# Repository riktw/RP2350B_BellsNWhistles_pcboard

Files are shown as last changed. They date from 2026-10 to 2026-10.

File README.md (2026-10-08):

## PCBoard for RP2350B BellsNWhistles

This contains the kicad files for a little board that turns the [RP2350B BellsNWhistles](https://github.com/riktw/RP2350B_BellsNWhistles) board into a small computer.
It has all the modern and some retro IO like:

- 3 x USB
- PS/2 for mouse and keyboard
- NES controller
- Audio via 3.5mm
- MicroSD for storage
- On board RTC

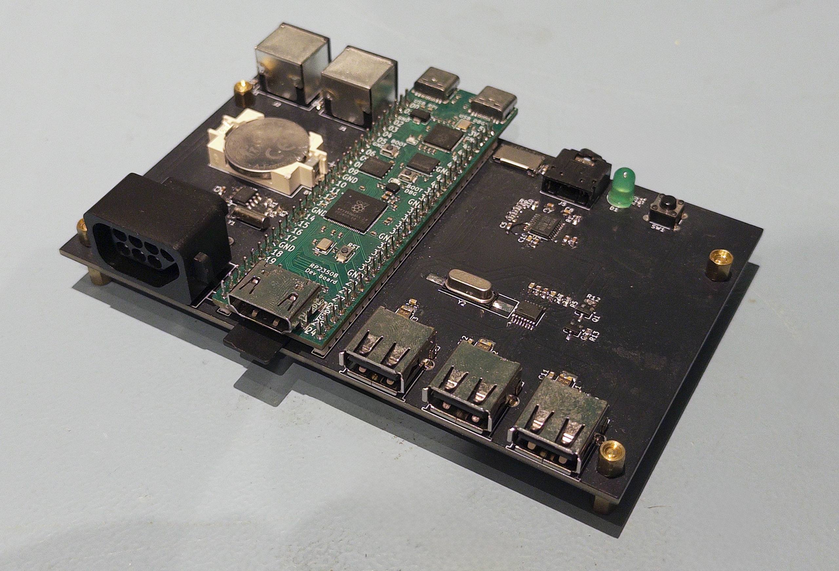
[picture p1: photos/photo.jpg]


This board is tested and no bugs should remain in the latest version.

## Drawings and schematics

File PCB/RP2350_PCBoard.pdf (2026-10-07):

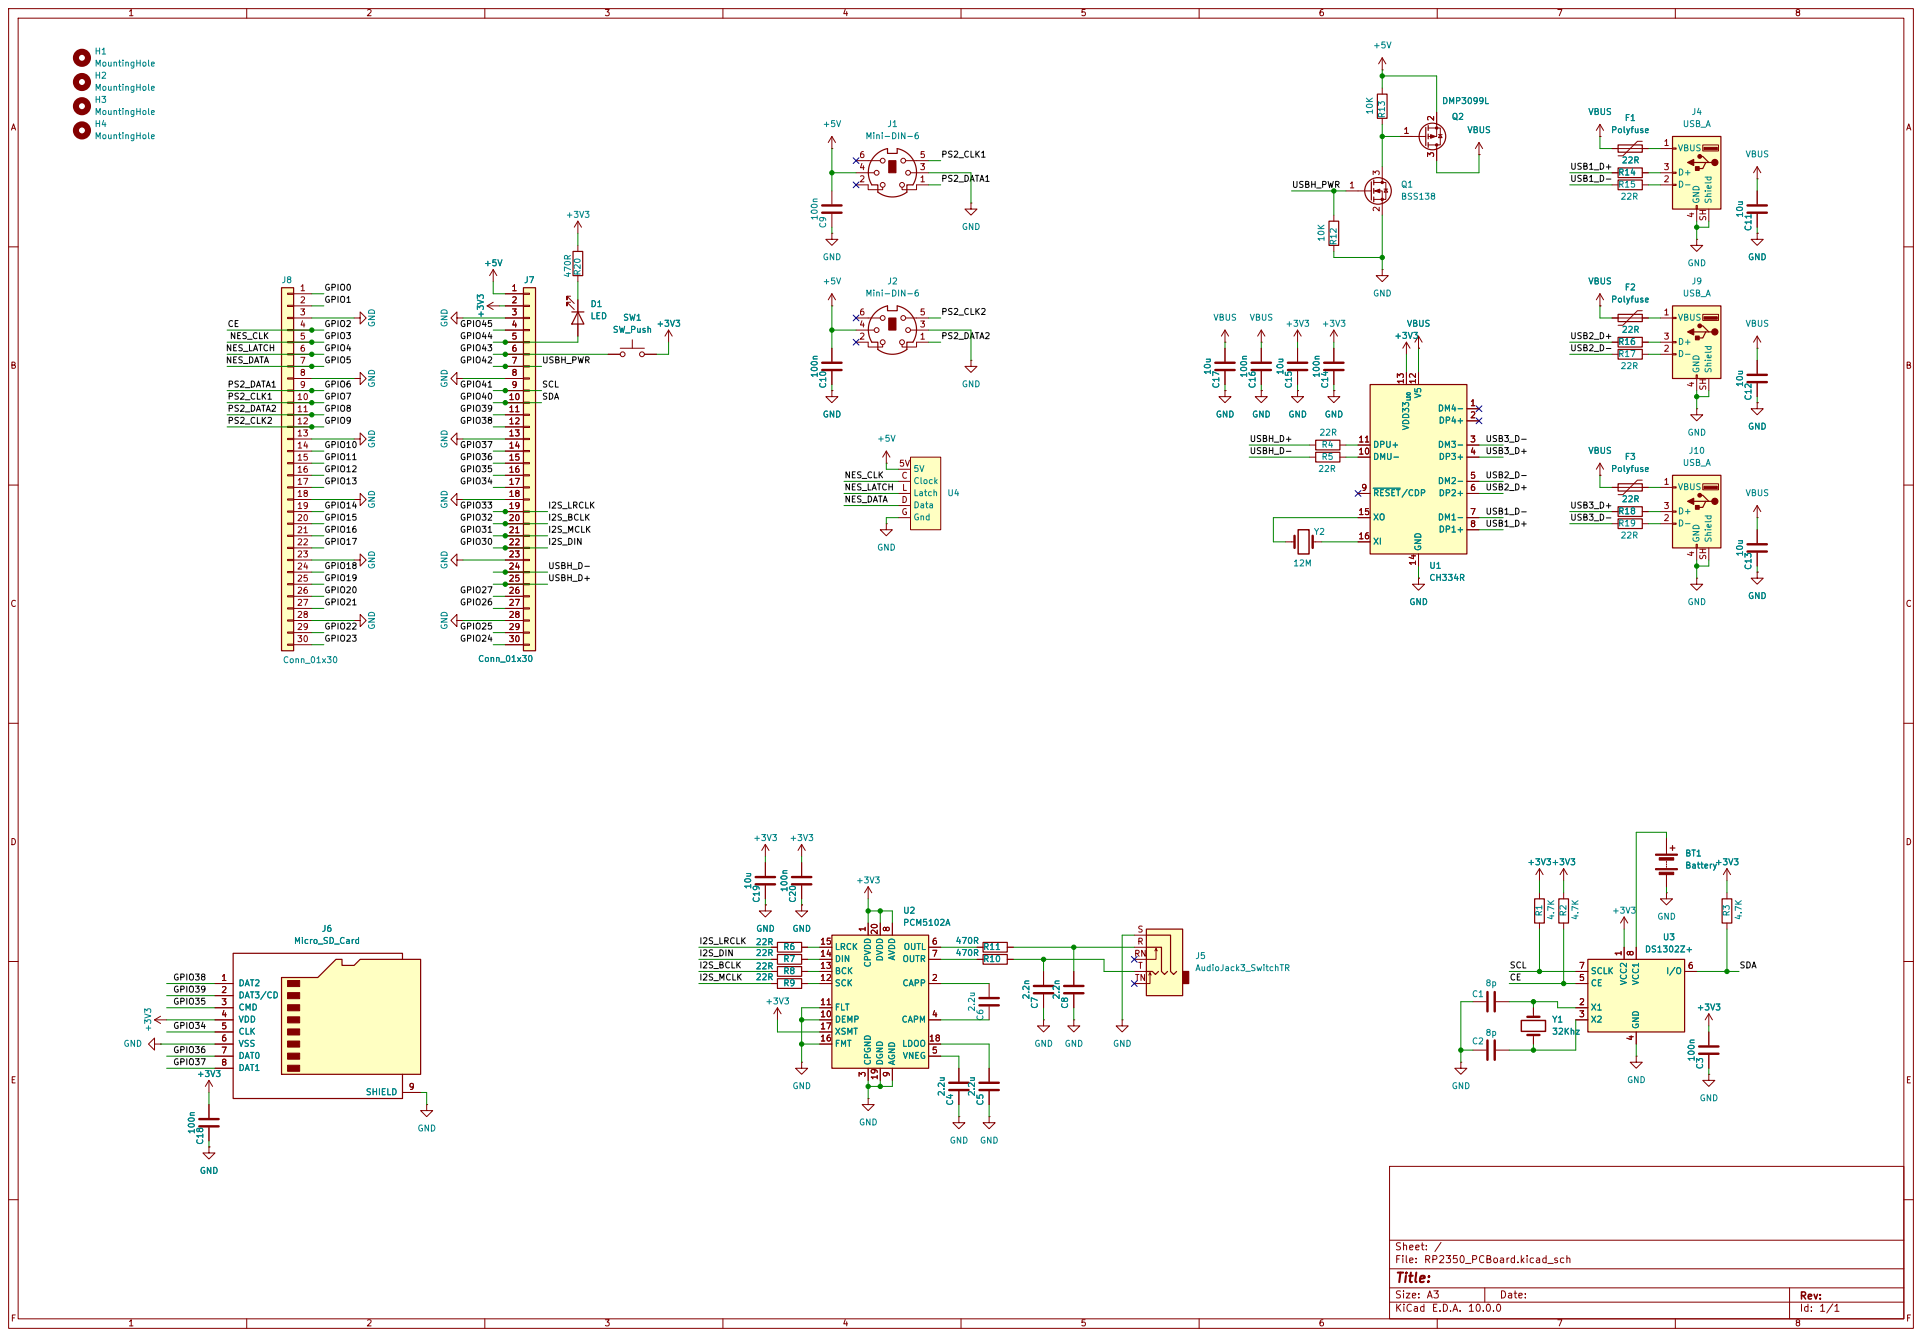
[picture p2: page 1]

Size: A3 | Rev: | F Date:
KiCad E.D.A. 10.0.0 | Id: 1/1

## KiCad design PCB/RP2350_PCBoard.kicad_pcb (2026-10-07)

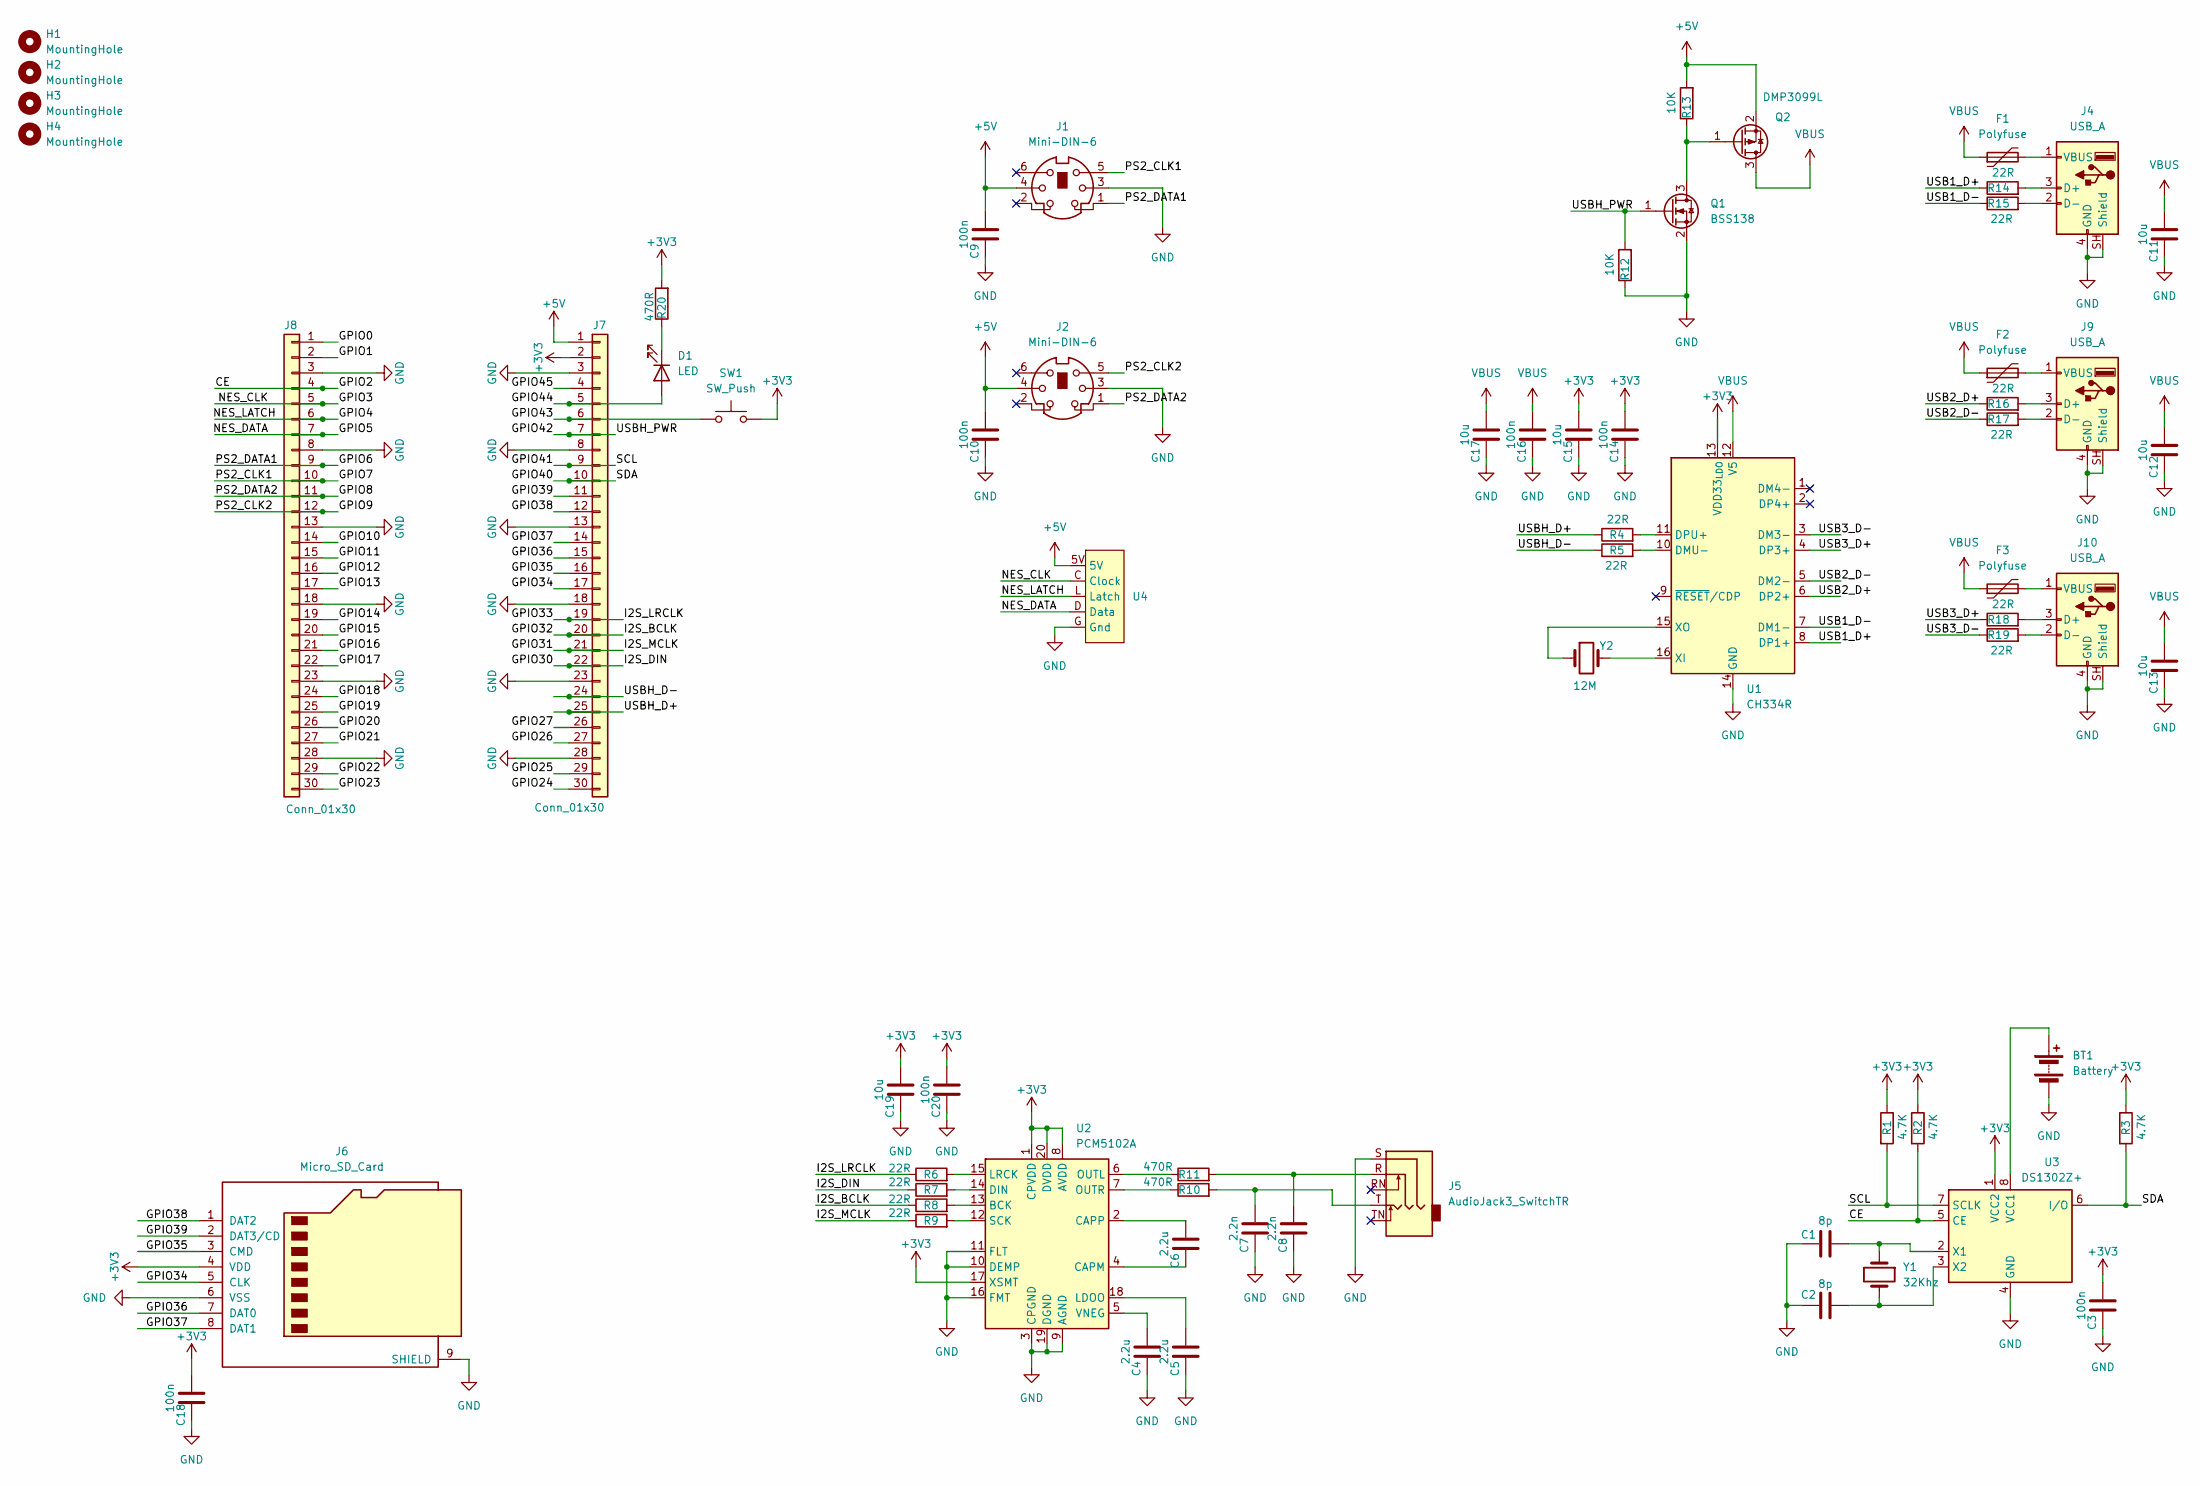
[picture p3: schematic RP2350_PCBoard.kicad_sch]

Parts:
BT1: Battery; BatteryHolder_Keystone_1060_1x2032; LCSC C70377
C1, C2: 8p; C_0603_1608Metric_Pad1.08x0.95mm_HandSolder
C3, C9, C10, C14, C16, C18, C20: 100n; C_0603_1608Metric_Pad1.08x0.95mm_HandSolder
C4, C5, C6: 2.2u; C_0603_1608Metric_Pad1.08x0.95mm_HandSolder
C7, C8: 2.2n; C_0603_1608Metric_Pad1.08x0.95mm_HandSolder
C11, C12, C13, C15, C17, C19: 10u; C_0603_1608Metric_Pad1.08x0.95mm_HandSolder
D1: LED; LED_D5.0mm
F1, F2, F3: Polyfuse; C_1812_4532Metric_Pad1.57x3.40mm_HandSolder
H1, H2, H3, H4: MountingHole; MountingHole_3.2mm_M3
J1, J2: Mini-DIN-6; Connector_Mini-DIN_Female_6Pin_2rows
J4, J9, J10: USB_A; USB_A_Molex_67643_Horizontal
J5: AudioJack3_SwitchTR; Jack_3.5mm_CUI_SJ1-3525N_Horizontal
J6: Micro_SD_Card; microSD Hanbo Electronic TF-018; LCSC C961679
J7, J8: Conn_01x30; PinHeader_1x30_P2.54mm_Vertical
Q1: BSS138; SOT-23_Handsoldering; LCSC C82045
Q2: DMP3099L; SOT-23_Handsoldering; LCSC C148354
R1, R2, R3: 4.7K; R_0603_1608Metric_Pad0.98x0.95mm_HandSolder
R4, R5, R6, R7, R8, R9, R14, R15, R16, R17, R18, R19: 22R; R_0603_1608Metric_Pad0.98x0.95mm_HandSolder
R10, R11, R20: 470R; R_0603_1608Metric_Pad0.98x0.95mm_HandSolder
R12, R13: 10K; R_0603_1608Metric_Pad0.98x0.95mm_HandSolder
SW1: SW_Push; SW_PUSH_6mm_H5mm
U1: CH334R; QSOP-16_3.9x4.9mm_P0.635mm; LCSC C4154405
U2: PCM5102A; TSSOP-20_4.4x6.5mm_P0.65mm; LCSC C107671
U3: DS1302Z+; SOIC-8_3.9x4.9mm_P1.27mm; LCSC C8959
U4: NES controller port
Y1: 32Khz; Crystal_DS26_D2.0mm_L6.0mm_Horizontal; LCSC C52082
Y2: 12M; Crystal_SMD_HC49-SD_HandSoldering; LCSC C14871

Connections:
+3V3: C3.2, C14.2, C15.2, C18.2, C19.2, C20.2, J6.4 (VDD), J7.2, R1.1, R2.1, R3.1, R20.2, SW1.2, U1.13 (VDD33_{LDO}), U2.1 (CPVDD), U2.8 (AVDD), U2.17 (XSMT), U2.20 (DVDD), U3.1 (VCC2)
+5V: C9.2, C10.2, J1.4, J2.4, J7.1, Q2.2 (S), R13.2, U4.5V
/CE: J8.4, R2.2, U3.5 (CE)
/GPIO0: J8.1
/GPIO1: J8.2
/GPIO3: J8.5, U4.C (Clock)
/GPIO4: J8.6, U4.L (Latch)
/GPIO5: J8.7, U4.D (Data)
/GPIO6: J1.1, J8.9
/GPIO7: J1.5, J8.10
/GPIO8: J2.1, J8.11
/GPIO9: J2.5, J8.12
/GPIO10: J8.14
/GPIO11: J8.15
/GPIO12: J8.16
/GPIO13: J8.17
/GPIO14: J8.19
/GPIO15: J8.20
/GPIO16: J8.21
/GPIO17: J8.22
/GPIO18: J8.24
/GPIO19: J8.25
/GPIO20: J8.26
/GPIO21: J8.27
/GPIO22: J8.29
/GPIO23: J8.30
/GPIO24: J7.30
/GPIO25: J7.29
/GPIO26: J7.27
/GPIO27: J7.26
/GPIO30: J7.22, R7.1
/GPIO31: J7.21, R9.1
/GPIO32: J7.20, R8.1
/GPIO33: J7.19, R6.1
/GPIO34: J6.5 (CLK), J7.17
/GPIO35: J6.3 (CMD), J7.16
/GPIO36: J6.7 (DAT0), J7.15
/GPIO37: J6.8 (DAT1), J7.14
/GPIO38: J6.1 (DAT2), J7.12
/GPIO39: J6.2 (DAT3/CD), J7.11
/GPIO40: J7.10, R3.2, U3.6 (I/O)
/GPIO41: J7.9, R1.2, U3.7 (SCLK)
/GPIO42: J7.7, Q1.1 (G), R12.2
/GPIO43: J7.6, SW1.1
/GPIO44: D1.2 (A), J7.5
/GPIO45: J7.4
/USB1_D+: R14.1, U1.8 (DP1+)
/USB1_D-: R15.1, U1.7 (DM1-)
/USB2_D+: R16.1, U1.6 (DP2+)
/USB2_D-: R17.1, U1.5 (DM2-)
/USB3_D+: R18.1, U1.4 (DP3+)
/USB3_D-: R19.1, U1.3 (DM3-)
/USBH_D+: J7.25, R4.1
/USBH_D-: J7.24, R5.1
GND: BT1.2 (-), C1.1, C2.1, C3.1, C4.1, C5.1, C7.1, C8.1, C9.1, C10.1, C11.1, C12.1, C13.1, C14.1, C15.1, C16.1, C17.1, C18.1, C19.1, C20.1, J1.3, J2.3, J4.4 (GND), J4.SH (Shield), J5.S, J6.6 (VSS), J6.9 (SHIELD), J7.3, J7.8, J7.13, J7.18, J7.23, J7.28, J8.3, J8.8, J8.13, J8.18, J8.23, J8.28, J9.4 (GND), J9.SH (Shield), J10.4 (GND), J10.SH (Shield), Q1.2 (S), R12.1, U1.14 (GND), U2.3 (CPGND), U2.9 (AGND), U2.10 (DEMP), U2.11 (FLT), U2.16 (FMT), U2.19 (DGND), U3.4 (GND), U4.G (Gnd)
unnamed: BT1.1 (+), U3.8 (VCC1)
unnamed: C7.2, J5.T, R10.2
unnamed: C8.2, J5.R, R11.2
unnamed: D1.1 (K), R20.1
unnamed: J4.3 (D+), R14.2
unnamed: J4.2 (D-), R15.2
unnamed: F1.2, J4.1 (VBUS)
unnamed: J9.3 (D+), R16.2
unnamed: J9.2 (D-), R17.2
unnamed: F2.2, J9.1 (VBUS)
unnamed: J10.3 (D+), R18.2
unnamed: J10.2 (D-), R19.2
unnamed: F3.2, J10.1 (VBUS)
unnamed: Q1.3 (D), Q2.1 (G), R13.1
unnamed: R5.2, U1.10 (DMU-)
unnamed: R4.2, U1.11 (DPU+)
unnamed: U1.16 (XI), Y2.2
unnamed: U1.15 (XO), Y2.1
unnamed: R8.2, U2.13 (BCK)
unnamed: C6.1, U2.4 (CAPM)
unnamed: C6.2, U2.2 (CAPP)
unnamed: R7.2, U2.14 (DIN)
unnamed: C5.2, U2.18 (LDOO)
unnamed: R6.2, U2.15 (LRCK)
unnamed: R11.1, U2.6 (OUTL)
unnamed: R10.1, U2.7 (OUTR)
unnamed: R9.2, U2.12 (SCK)
unnamed: C4.2, U2.5 (VNEG)
unnamed: C1.2, U3.2 (X1), Y1.1
unnamed: C2.2, U3.3 (X2), Y1.2
VBUS: C11.2, C12.2, C13.2, C16.2, C17.2, F1.1, F2.1, F3.1, Q2.3 (D), U1.12 (V5)

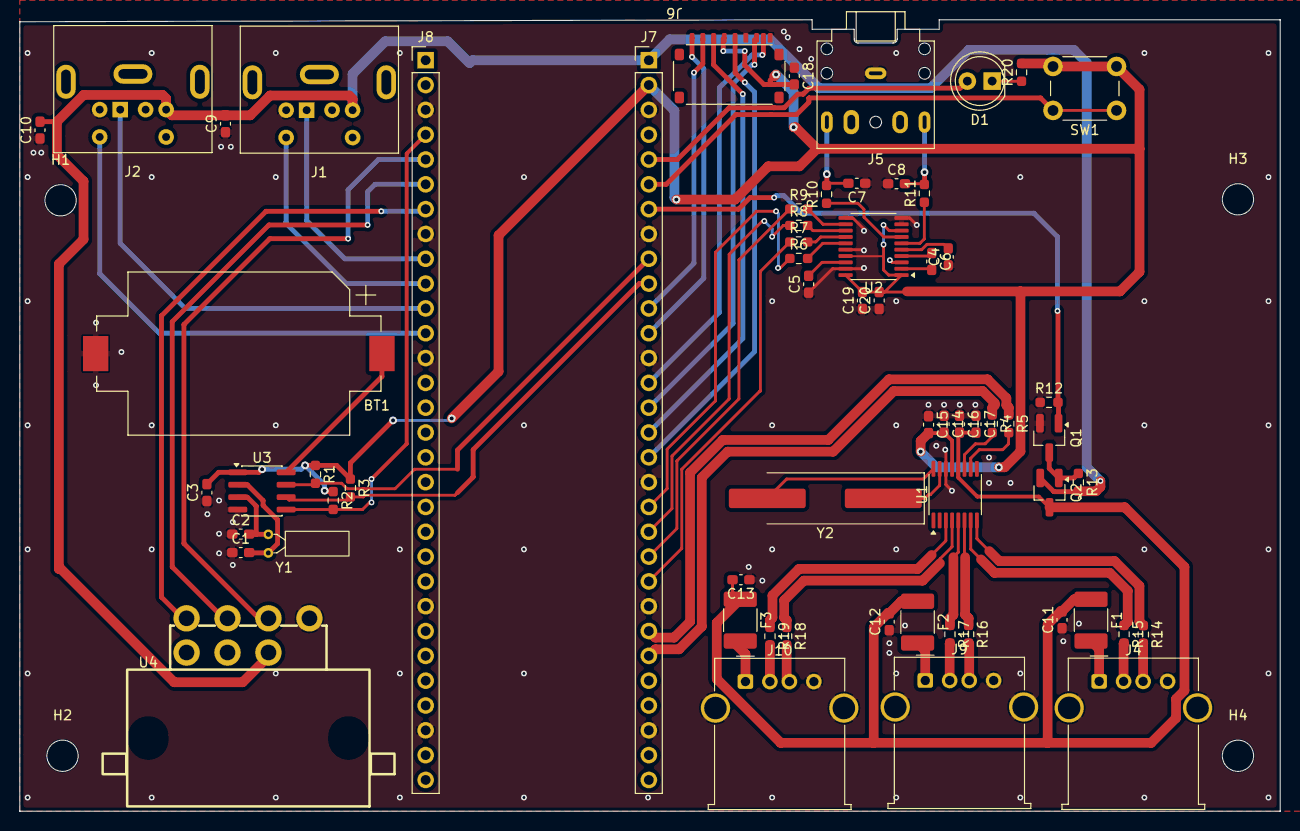
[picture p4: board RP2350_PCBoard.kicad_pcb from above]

Board: 2 copper layers, 129.0 x 81.0 mm, 67 parts (0 on the bottom side), 65 nets.
